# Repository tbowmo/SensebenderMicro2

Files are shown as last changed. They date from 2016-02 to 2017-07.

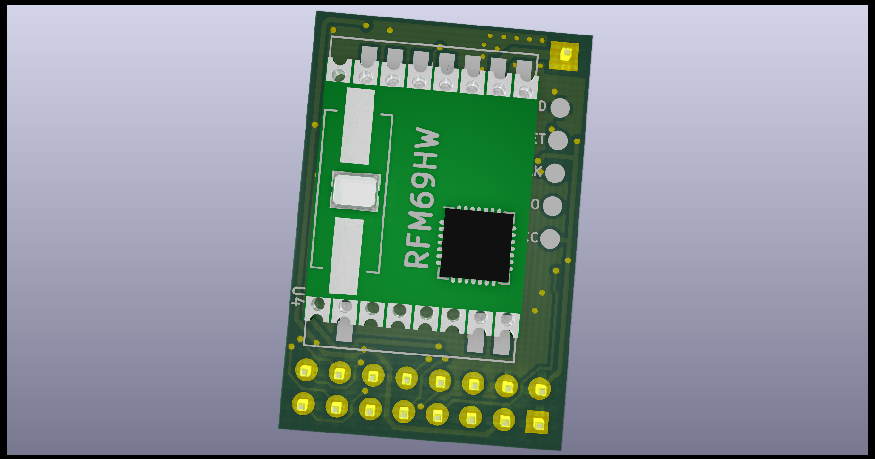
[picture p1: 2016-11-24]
SensebenderV2-bottom-rfm69.png

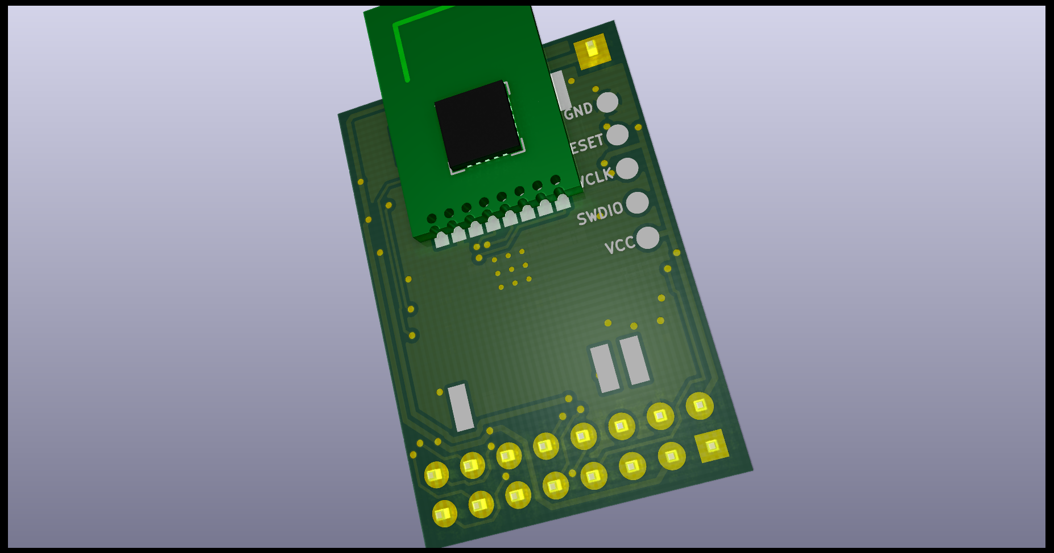
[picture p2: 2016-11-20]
SensebenderV2-bottom.png

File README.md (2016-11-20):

## Sensebender Micro v2

Revamped Sensebender Micro, with Atmel SAMD20 processor instead of atmega 328p.

Enhancements over old Sensebender:

- up to 256Kb flash/32Kb RAM for code
- up to 48Mhz operating freq.
- 2 LEDs
- Dual radio
  - RFM69
  - NRF24 mini / smd
- onboard voltage regulator, can be disabled / bypassed with solderbridges
- Temperature / Humidity sensor Si7021
- Onboard external flash for future OTA (bootloader is not developed yet)
- Use [MYSX2.4](https://www.mysensors.org/hardware/mysx#mysx-24) connector for add-on boards

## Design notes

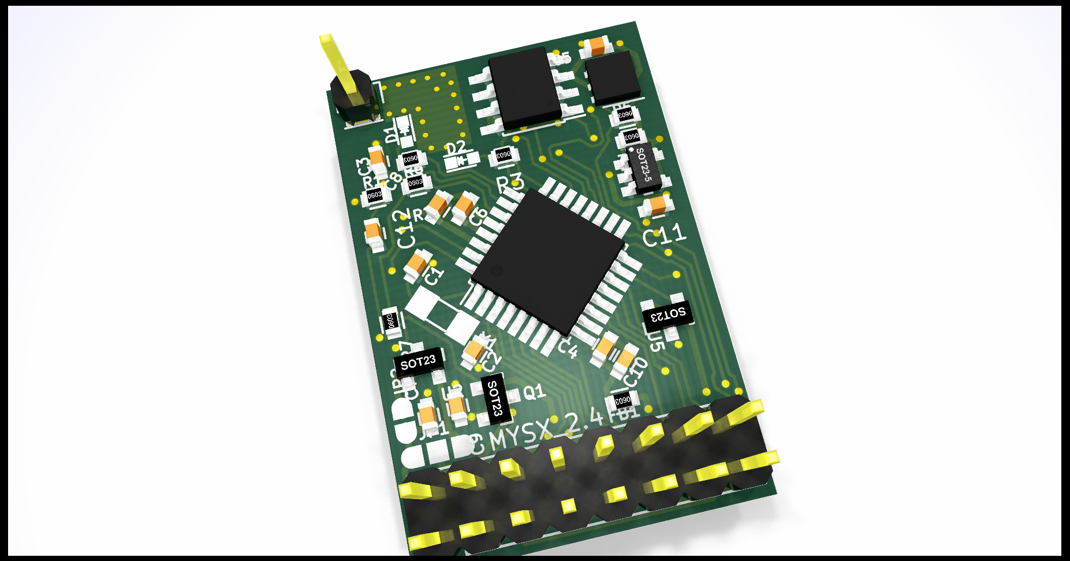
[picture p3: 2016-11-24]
SensebenderV2-top.png

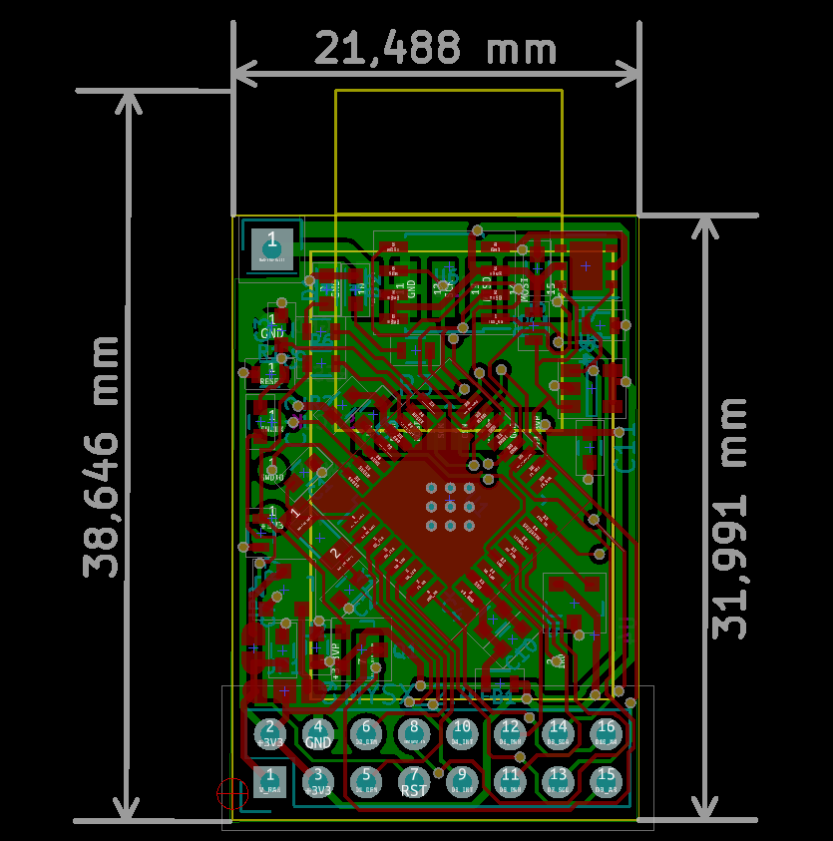
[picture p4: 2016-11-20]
SensebenderV2-dimensions.png

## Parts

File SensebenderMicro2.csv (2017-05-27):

Source: | /home/thomas/Projects/kicad/SensebenderMicro2/SensebenderMicro2.sch
Date: | lør 27 maj 2017 07:43:58 CEST
Tool: | Eeschema no-vcs-found-5e5259b~58~ubuntu16.10.1
Generator: | /home/thomas/.kicad_plugins/pf_bom_csv_grouped_by_value.py
Component Count: | 40
Ref | Qnty | Value | Cmp name | Footprint | Description | Vendor | Vendor part | Supplier1 | Supplier1 part | Supplier1 link | Supplier2 | Supplier2 part | Supplier2 link | Supplier3 | Supplier3 part | Supplier3 link | Supplier4 | Supplier4 part | Supplier4 link
C1, C2, C6, C5, C4, C8, C7, C9, C13, | 9 | 100nF | C | Capacitors_SMD:C_0603 | Unpolarized capacitor
C3, | 1 | 10nF | C | Capacitors_SMD:C_0603 | Unpolarized capacitor
C10, C11, C14, | 3 | 10uF | CP | Capacitors_SMD:C_0603 | Polarised capacitor
C12, | 1 | C | C | Capacitors_SMD:C_0603 | Unpolarized capacitor
D1, D3, | 2 | LED | LED-RESCUE-SensebenderMicro2 | LEDs:LED-0603
FB1, | 1 | FILTER | FILTER | Resistors_SMD:R_0603 |  | Murata | BLM18PG471SN1D
JP1, | 1 | PWR SELECT | JUMPER3 | mysensors_obscurities:3_pin_solder_jumper_smd
JP2, | 1 | JUMPER | JUMPER | mysensors_obscurities:2_pin_solder_jumper_smd
P2, | 1 | MYSX_2.4 | MYSX_2.4 | mysensors_connectors:MYSX_1.3 | Mysensors expansion connector 2.4
P3, | 1 | Antenna | CONN_01X02 | Pin_Headers:Pin_Header_Angled_1x02 | Connector, single row, 01x02, pin header
R1, | 1 | 100K | R | Resistors_SMD:R_0603 | Resistor
R2, R6, | 2 | 220R | R | Resistors_SMD:R_0603 | Resistor
R4, R5, | 2 | 4k7 | R | Resistors_SMD:R_0603 | Resistor
U1, | 1 | ATSAMD20E | ATSAMD21E | Housings_QFP:TQFP-32_7x7mm_Pitch0.8mm | Atmel ATSAM D21E | Atmel | ATSAMD20E18A-AN
U2, | 1 | MCP1703T-3302E | AP1117D33 | Housings_SOT-23_SOT-143_TSOT-6:SOT-23 |  | Microchip | MCP1703T-3302E/CB
U3, | 1 | NRF24L01 | NRF24L01 | mysensors_radios:NRF24L01-SMD | NRF24L01+
U4, | 1 | RFM69HW | RFM69HW | mysensors_radios:RFM69HW_SMD_Handsoldering | RFM69HW, 868Mhz +20dBm HopeRF Wireless Transceiver, Vcc=3.3V
U5, | 1 | ATSHA204A | ATSHA204A | TO_SOT_Packages_SMD:SOT-23_Handsoldering | ATSHA204A, Secure Authentication and Validation Device, SOT-23, Vcc=3.3V | Micrhochip | ATSHA204A-STUCZ-T
U6, | 1 | AT45DB041E | AT25DF512C | Housings_SOIC:SOIC-8_3.9x4.9mm_Pitch1.27mm | AT25DF512C, 512-Kbit SPI Serial Flash Memory, SOIC-8, Vcc=3.3V | atmel | atmel
U7, | 1 | Si7021 | Si7021 | Housings_DFN_QFN:DFN-6-1EP_3x3mm_Pitch0.95mm | Humidity / Temperature sensor | Silicon | Si7041
U8, | 1 | 24AA32AT-I/OT | AT24C32-STUM-T | TO_SOT_Packages_SMD:SOT-23-5 | AT24C32-STUM-T, 32-Kbit I2C Eeprom, SOT23-5, Vcc=2.5-5V | Microchip | 24AA32AT-I/OT
W1, | 1 | GND | TEST_1P | Measurement_Points:Measurement_Point_Round-SMD-Pad_Small | point
W2, | 1 | RESET | TEST_1P | Measurement_Points:Measurement_Point_Round-SMD-Pad_Small | point
W3, | 1 | SWCLK | TEST_1P | Measurement_Points:Measurement_Point_Round-SMD-Pad_Small | point
W4, | 1 | SWDIO | TEST_1P | Measurement_Points:Measurement_Point_Round-SMD-Pad_Small | point
W5, | 1 | VCC | TEST_1P | Measurement_Points:Measurement_Point_Round-SMD-Pad_Small | point
Y1, | 1 | 32Khz | Crystal_Small | mysensors_obscurities:XTAL_3.2x1.5mm | Two pin crystal, small symbol | Abracon

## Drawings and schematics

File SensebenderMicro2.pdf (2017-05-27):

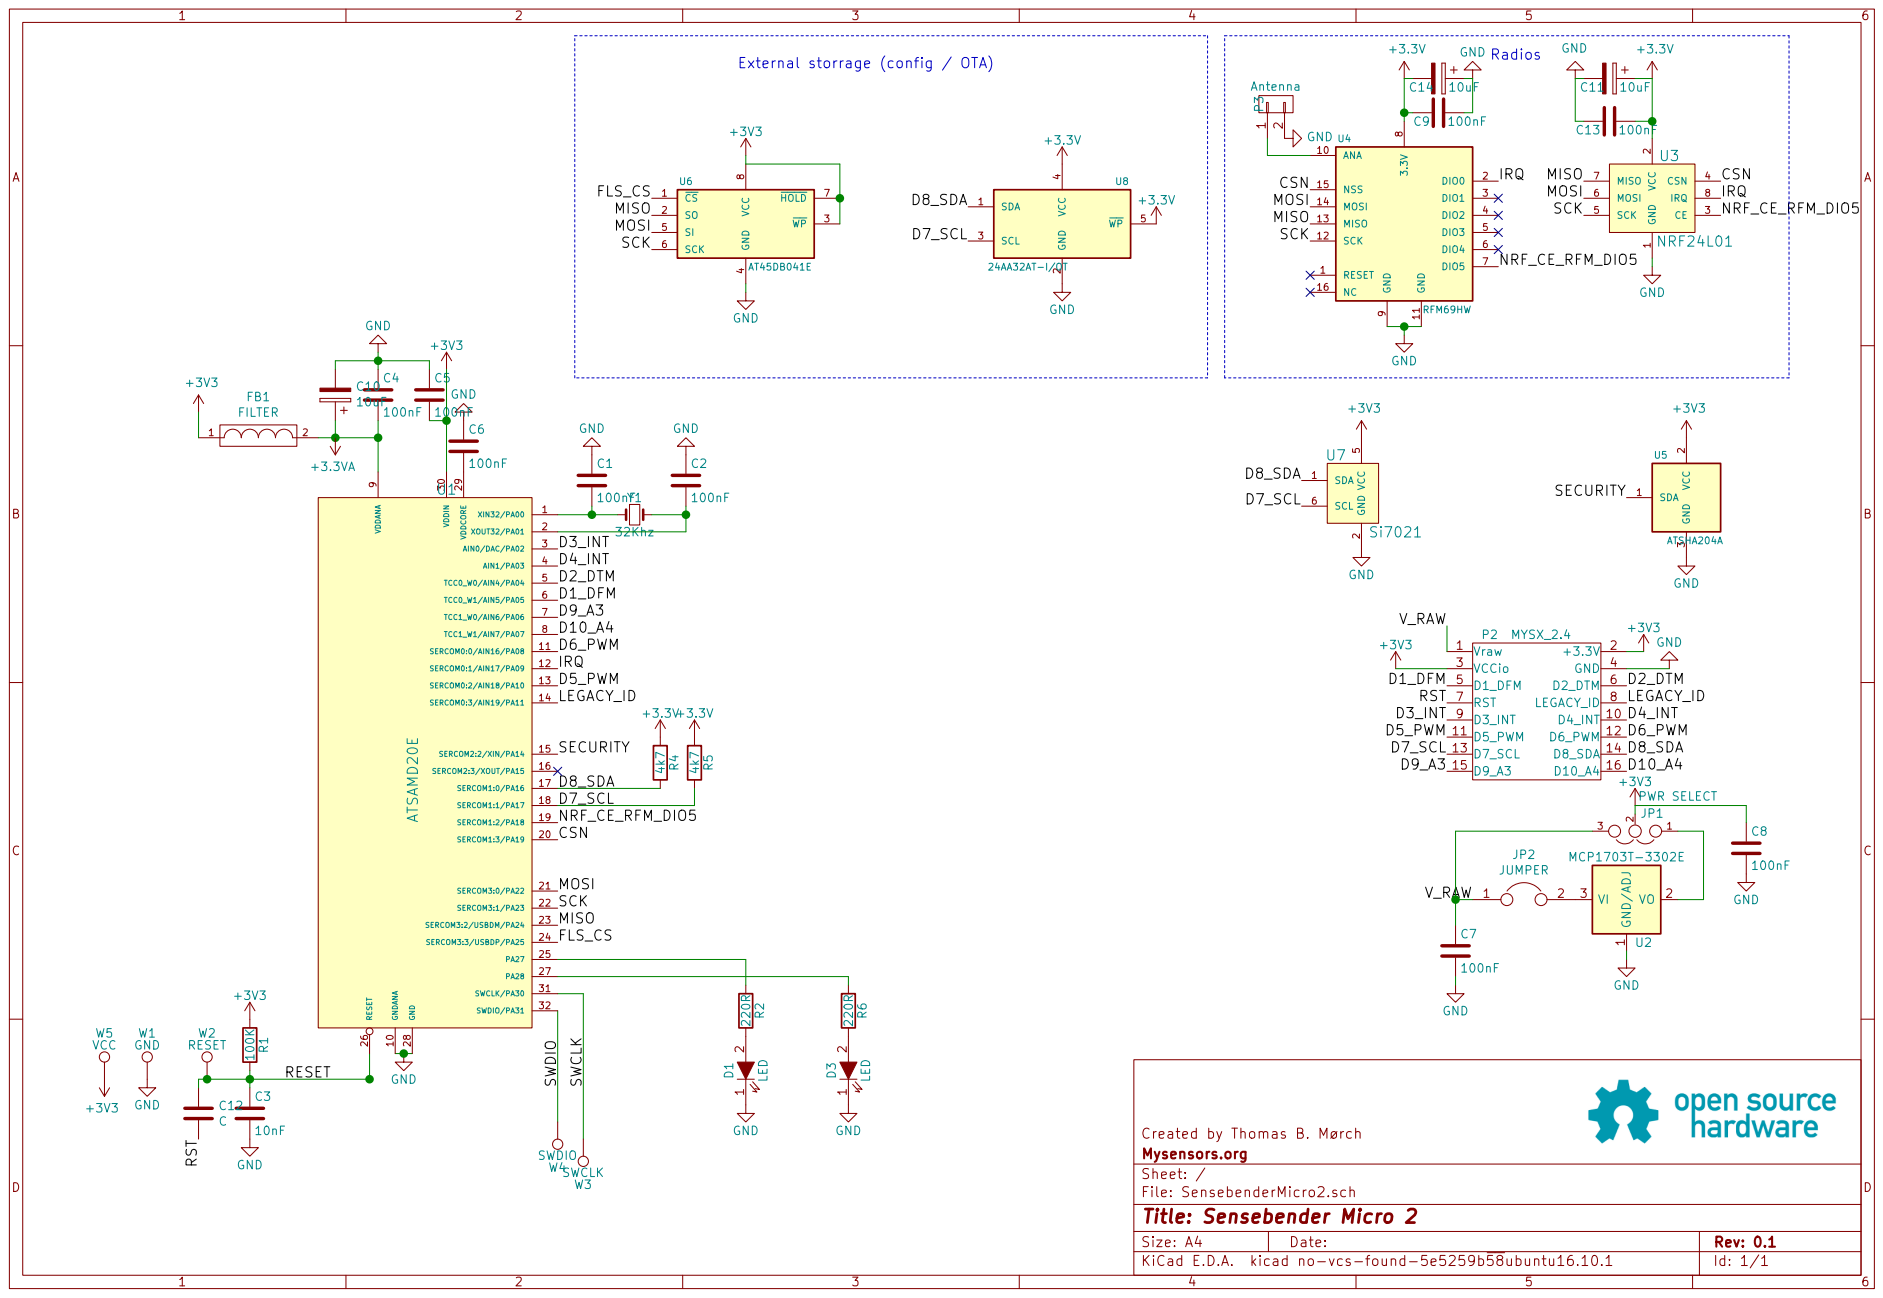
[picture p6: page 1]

9 ANA 10 GND 11 SCK 12 MISO 13 MOSI 14 NSS 15 NC 16 U4 RFM69HW GND

2 CE 3 CSN 4 SCK 5 MOSI 6 MISO 7

4 SI 5 SCK 6 HOLD 7 VCC

File: SensebenderMicro2.sch Sheet: / Mysensors.org

Id: 1/1 Title: Sensebender Micro 2

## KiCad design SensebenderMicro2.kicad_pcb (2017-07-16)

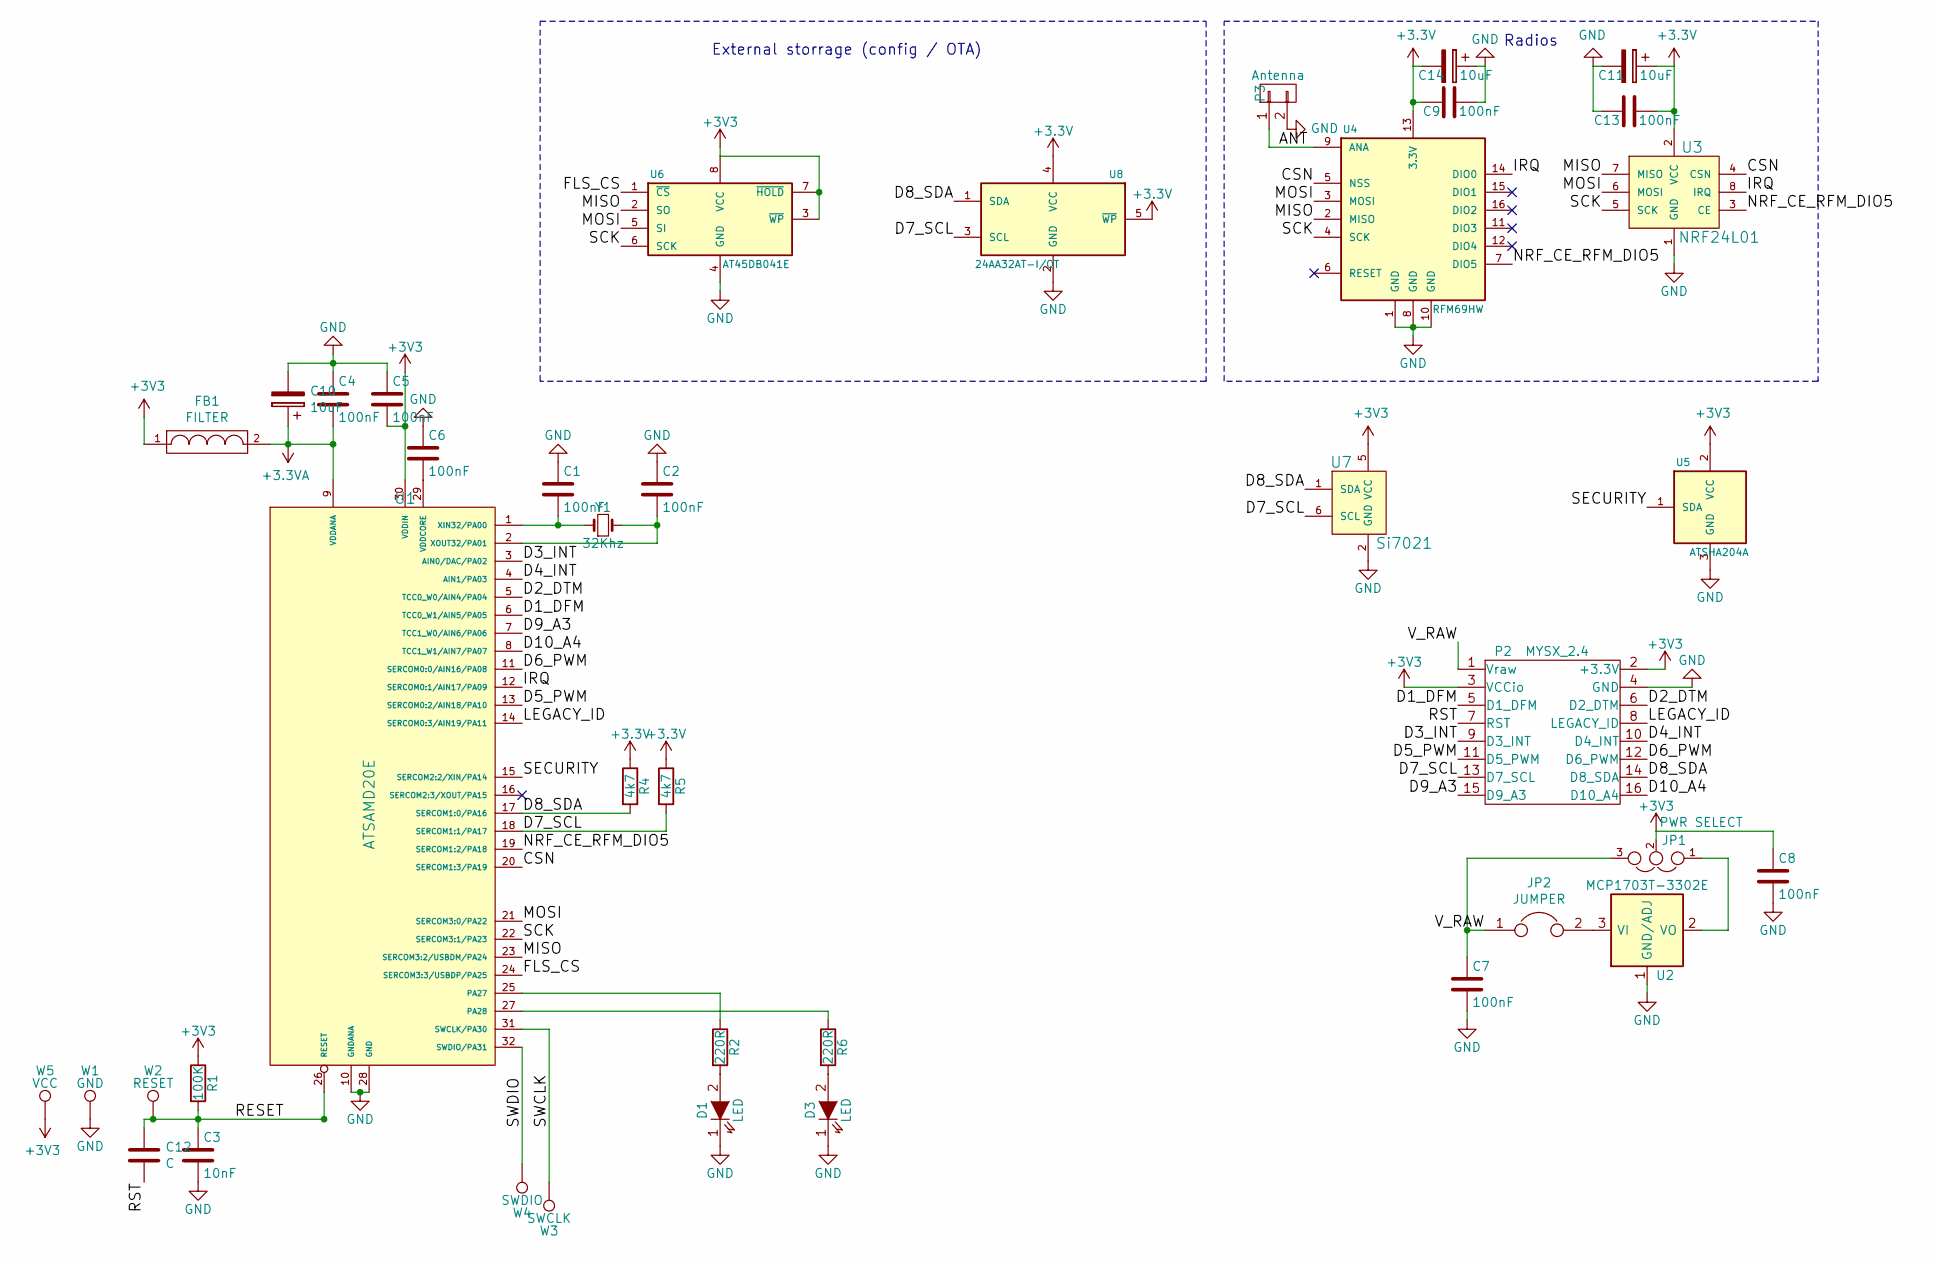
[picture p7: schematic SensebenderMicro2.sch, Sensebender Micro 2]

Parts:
C1, C2, C4, C5, C6, C7, C8, C9, C13: 100nF; C_0603
C3: 10nF; C_0603
C10, C11, C14: 10uF; C_0603
C12: C; C_0603
D1, D3: LED; LED-0603
FB1: FILTER; R_0603
JP1: PWR SELECT; 3_pin_solder_jumper_smd
JP2: JUMPER; 2_pin_solder_jumper_smd
P2: MYSX_2.4; MYSX_1.3
P3: Antenna; Pin_Header_Angled_1x02
R1: 100K; R_0603
R2, R6: 220R; R_0603
R4, R5: 4k7; R_0603
U1: ATSAMD20E; TQFP-32_7x7mm_Pitch0.8mm
U2: MCP1703T-3302E; SOT-23
U3: NRF24L01; NRF24L01-SMD
U4: RFM69HW; RFM69HW_SMD_Handsoldering
U5: ATSHA204A; SOT-23_Handsoldering
U6: AT45DB041E; SOIC-8_3.9x4.9mm_Pitch1.27mm
U7: Si7021; DFN-6-1EP_3x3mm_Pitch0.95mm
U8: 24AA32AT-I/OT; SOT-23-5
W1: GND; Measurement_Point_Round-SMD-Pad_Small
W2: RESET; Measurement_Point_Round-SMD-Pad_Small
W3: SWCLK; Measurement_Point_Round-SMD-Pad_Small
W4: SWDIO; Measurement_Point_Round-SMD-Pad_Small
W5: VCC; Measurement_Point_Round-SMD-Pad_Small
Y1: 32Khz; XTAL_3.2x1.5mm

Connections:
+3.3VA: C4.2, C10.1, FB1.2, U1.9 (VDDANA)
/ANT: P3.1, U4.9 (ANA)
/CSN: U1.20 (SERCOM1:3/PA19), U3.4 (CSN), U4.5 (NSS)
/D1_DFM: P2.5 (D1_DFM), U1.6 (TCC0_W1/AIN5/PA05)
/D2_DTM: P2.6 (D2_DTM), U1.5 (TCC0_W0/AIN4/PA04)
/D3_INT: P2.9 (D3_INT), U1.3 (AIN0/DAC/PA02)
/D4_INT: P2.10 (D4_INT), U1.4 (AIN1/PA03)
/D5_PWM: P2.11 (D5_PWM), U1.13 (SERCOM0:2/AIN18/PA10)
/D6_PWM: P2.12 (D6_PWM), U1.11 (SERCOM0:0/AIN16/PA08)
/D7_SCL: P2.13 (D7_SCL), R5.2, U1.18 (SERCOM1:1/PA17), U7.6 (SCL), U8.3 (SCL)
/D8_SDA: P2.14 (D8_SDA), R4.2, U1.17 (SERCOM1:0/PA16), U7.1 (SDA), U8.1 (SDA)
/D9_A3: P2.15 (D9_A3), U1.7 (TCC1_W0/AIN6/PA06)
/D10_A4: P2.16 (D10_A4), U1.8 (TCC1_W1/AIN7/PA07)
/FLS_CS: U1.24 (SERCOM3:3/USBDP/PA25), U6.1 (~CS)
/IRQ: U1.12 (SERCOM0:1/AIN17/PA09), U3.8 (IRQ), U4.14 (DIO0)
/LEGACY_ID: P2.8 (LEGACY_ID), U1.14 (SERCOM0:3/AIN19/PA11)
/MISO: U1.23 (SERCOM3:2/USBDM/PA24), U3.7 (MISO), U4.2 (MISO), U6.2 (SO)
/MOSI: U1.21 (SERCOM3:0/PA22), U3.6 (MOSI), U4.3 (MOSI), U6.5 (SI)
/NRF_CE_RFM_DIO5: U1.19 (SERCOM1:2/PA18), U3.3 (CE), U4.7 (DIO5)
/RESET: C3.1, C12.1, R1.2, U1.26 (RESET), W2.1
/RST: C12.2, P2.7 (RST)
/SCK: U1.22 (SERCOM3:1/PA23), U3.5 (SCK), U4.4 (SCK), U6.6 (SCK)
/SECURITY: U1.15 (SERCOM2:2/XIN/PA14), U5.1 (SDA)
/SWCLK: U1.31 (SWCLK/PA30), W3.1
/SWDIO: U1.32 (SWDIO/PA31), W4.1
/V_RAW: C7.1, JP1.3, JP2.1, P2.1 (Vraw)
GND: C1.1, C2.1, C3.2, C4.1, C5.1, C6.1, C7.2, C8.2, C9.1, C10.2, C11.2, C13.2, C14.1, D1.1 (K), D3.1 (K), P2.4 (GND), P3.2, U1.10 (GNDANA), U1.28 (GND), U2.1 (GND/ADJ), U3.1 (GND), U4.1 (GND), U4.8 (GND), U4.10 (GND), U5.3 (GND), U6.4 (GND), U7.2 (GND), U8.2 (GND), W1.1
unnamed: C1.2, U1.1 (XIN32/PA00), Y1.1
unnamed: C2.2, U1.2 (XOUT32/PA01), Y1.2
unnamed: C6.2, U1.29 (VDDCORE)
unnamed: D1.2 (A), R2.2
unnamed: D3.2 (A), R6.2
unnamed: JP1.1, U2.2 (VO)
unnamed: JP2.2, U2.3 (VI)
unnamed: R2.1, U1.25 (PA27)
unnamed: R6.1, U1.27 (PA28)

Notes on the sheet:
Radios
External storrage (config / OTA)

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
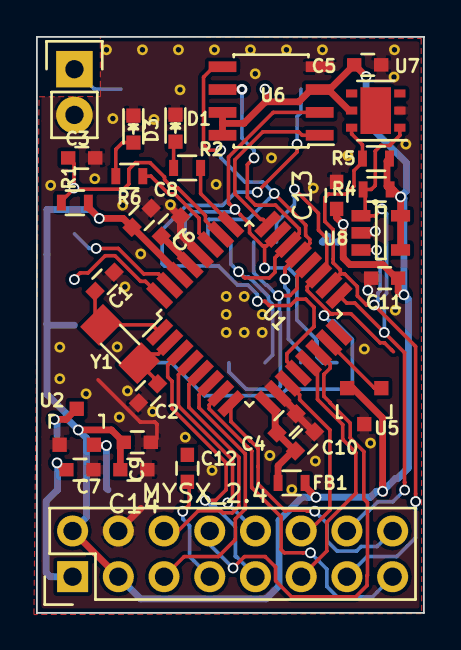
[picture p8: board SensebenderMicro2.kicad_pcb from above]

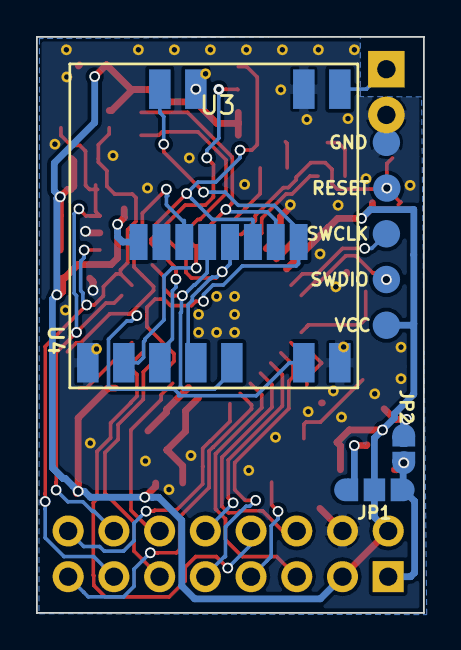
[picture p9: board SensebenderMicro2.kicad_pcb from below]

Board: 2 copper layers, 21.5 x 32.0 mm, 40 parts (9 on the bottom side), 37 nets.

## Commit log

2016-02-12 Added testpads to reset signal + gnd
    [MysensorsMicro2.kicad_pcb, MysensorsMicro2.sch]
2016-02-13 Renamed to SensebenderMicro2
    [SensebenderMicro2.kicad_pcb, SensebenderMicro2.sch]
2016-03-16 Added filtering for analog supply
    [SensebenderMicro2.kicad_pcb, SensebenderMicro2.sch]
2016-05-01 Added fet to switch power to radio / ATSHA
    [SensebenderMicro2.kicad_pcb, SensebenderMicro2.sch]
2016-05-02 Added Gate pull up and series resistor to Q1
    [SensebenderMicro2.kicad_pcb, SensebenderMicro2.sch]
2016-05-02 Rerouted to make room for GND via at C7
    [SensebenderMicro2.kicad_pcb, SensebenderMicro2.sch]
2016-07-13 added reset / DIO5 connections to RFM69
    [SensebenderMicro2.kicad_pcb, SensebenderMicro2.sch]
2016-11-16 Updated to use MYSX2.x with reset
    Also shuffled peripherals around on the samd, to make routing easier
    [SensebenderMicro2.kicad_pcb, SensebenderMicro2.sch]
2016-11-16 Added pin analysis spreadsheet
    [pin-analysis.xlsx]
2016-11-16 Updated manufacturing preview files
    [SensebenderMicro2-B.Cu.gbr, SensebenderMicro2-B.Mask.gbr, SensebenderMicro2-B.SilkS.gbr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]
2016-11-18 updated silkscreen placements
    [SensebenderMicro2.kicad_pcb]
2016-11-20 recreated routing with better ground plane
    [SensebenderMicro2-B.Cu.gbr, SensebenderMicro2-B.Mask.gbr, SensebenderMicro2-B.SilkS.gbr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]
2016-11-24 Updated routing, waveguide for rfm69
    [SensebenderMicro2-B.Cu.gbr, SensebenderMicro2-B.Mask.gbr, SensebenderMicro2-B.SilkS.gbr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]
2016-11-27 Updated routing, gnd on component side
    [SensebenderMicro2-B.Cu.gbr, SensebenderMicro2-B.Mask.gbr, SensebenderMicro2-B.SilkS.gbr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]
2017-02-07 Updates to layout, copper pour etc
    [SensebenderMicro2-B.Cu.gbr, SensebenderMicro2-B.Mask.gbr, SensebenderMicro2-B.SilkS.gbr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]
2017-02-07 Added extra 10uF caps to radios
    [SensebenderMicro2-B.Cu.gbr, SensebenderMicro2-B.Mask.gbr, SensebenderMicro2-B.SilkS.gbr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]
2017-02-22 Updated gerbers, preparing for pcb ordering
    [SensebenderMicro2-B.Cu.gbr, SensebenderMicro2-B.Mask.gbr, SensebenderMicro2-B.SilkS.gbr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]
2017-05-27 Updated vendor references
    [SensebenderMicro2.sch]
2017-05-27 Added BOM file
    [SensebenderMicro2.csv]
2017-07-05 Changed to use RFM69HCW footprint (compatible with RFM95)
    [SensebenderMicro2.kicad_pcb, SensebenderMicro2.sch]
2017-07-16 Updated layout a bit
    [SensebenderMicro2.kicad_pcb]
